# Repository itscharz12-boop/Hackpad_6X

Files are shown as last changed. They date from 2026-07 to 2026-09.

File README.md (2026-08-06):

# Hackpad 6x

Hackpad 6x is a small but very over-engineered macropad that I designed because apparently a normal keyboard was not enough :)

The idea was to make a compact control pad that could do a bit of everything: media controls, shortcuts, gaming controls, numpad functions, and displaying useless (but cool) information from my PC.

Basically, I wanted an "infinite keys" macropad where a few buttons could become a lot of buttons through layers.

(Yes, this did start as "I'll just make a simple macropad" and then somehow became OLEDs, RGB, and a PC monitoring system. I have no idea how this happened.)

Images of this hackpad can be found in the "images" folder.

Showcase Video (For Hack Club's Stardance event) also available at this link:
https://drive.google.com/file/d/1NDWkFQftZgt32tnkIbqYFETVVm34cNFE/view?usp=sharing

---

# Quick Start

To build this:

1. **Build the hardware**
   - Assemble the PCB, switches, encoder, OLED and case.
   - (Of course you need a soldering iron for soldering. Unfortunately staring at the PCB does not make the components attach themselves.)

2. **Flash the firmware**
   - Install QMK and flash the firmware onto the Seeed XIAO RP2040.

3. **Install HackpadDataLink**
   - Run the Python script on your PC to send system information to the OLED.

---

# Features

- 5 different profiles/layers
- Rotary encoder with push button
- OLED display
- RGB lighting
- PC telemetry

The PC telemetry shows:
- CPU usage
- GPU usage
- Volume
- Brightness

(Useful for checking your PC performance without moving your eyes approximately 20cm up to look at your monitor.)

---

# Hardware

The hackpad is built around a Seeed XIAO RP2040.

Parts:

- Seeed XIAO RP2040
- 8x Cherry MX switches
- 8x keycaps
- EC11 rotary encoder
- OLED display
- RGB LEDs
- Custom PCB
- 3D printed case

---

# Assembly

### PCB Assembly

Solder all components onto the PCB:

- Diodes
- RGB LEDs
- OLED
- Rotary encoder
- XIAO RP2040

Please please please check the orientation twice, you won't regret it

### Case Assembly

- Install heat-set inserts
- Screw everything together

---

### Firmware

Hackpad 6x uses QMK firmware.

The firmware includes:

- Layer switching
- Encoder controls
- RGB effects
- OLED graphics
- RAW HID PC communication

---

### Hackpad DataLink

HackpadDataLink is a Python script that sends PC information to the hackpad.

Currently supported:

- CPU usage
- GPU usage
- Volume
- Brightness

---

# Images










### AI Usage

AI was used minimally throughout this project. The only instance of AI use was on 4 occasions fixing compile errors in the firmware. This was done with VS code's built in AI. Aside from this, no other AI tools were used in the making of this project.

Hackpad 6x was built as a personal project to learn PCB design, CAD, QMK firmware, and hardware/software integration.

Huge thanks to Hack Club for making this program possible :)

(Also thanks to Google, Stack Overflow, and whoever wrote the forum post that fixed kicad at 1am.)

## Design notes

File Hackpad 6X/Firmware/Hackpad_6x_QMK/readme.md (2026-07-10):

# hackpad_6x_qmk

hackpad_6x_qmk

*A short description of the keyboard/project*

* Keyboard Maintainer: [Charles Z](https://github.com/charz)
* Hardware Supported: *The PCBs, controllers supported*
* Hardware Availability: *Links to where you can find this hardware*

Make example for this keyboard (after setting up your build environment):

    make hackpad_6x_qmk:default

Flashing example for this keyboard:

    make hackpad_6x_qmk:default:flash

See the [build environment setup](https://docs.qmk.fm/#/getting_started_build_tools) and the [make instructions](https://docs.qmk.fm/#/getting_started_make_guide) for more information. Brand new to QMK? Start with our [Complete Newbs Guide](https://docs.qmk.fm/#/newbs).

## Bootloader

Enter the bootloader in 3 ways:

* **Bootmagic reset**: Hold down the key at (0,0) in the matrix (usually the top left key or Escape) and plug in the keyboard
* **Physical reset button**: Briefly press the button on the back of the PCB - some may have pads you must short instead
* **Keycode in layout**: Press the key mapped to `QK_BOOT` if it is available

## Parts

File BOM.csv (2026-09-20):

Component | Quantity
Seeed XIAO RP2040 | 1
Hackpad PCB | 1
MX-compatible switches | 8
MX-compatible keycaps | 8
EC11 rotary encoder | 1
0.91 inch I2C OLED | 1
SK6812 MINI-E LEDs | 18
Diodes | 9
M3 heat-set inserts | 6
M3 screws | 6
3D-printed case top | 1
3D-printed case base | 1

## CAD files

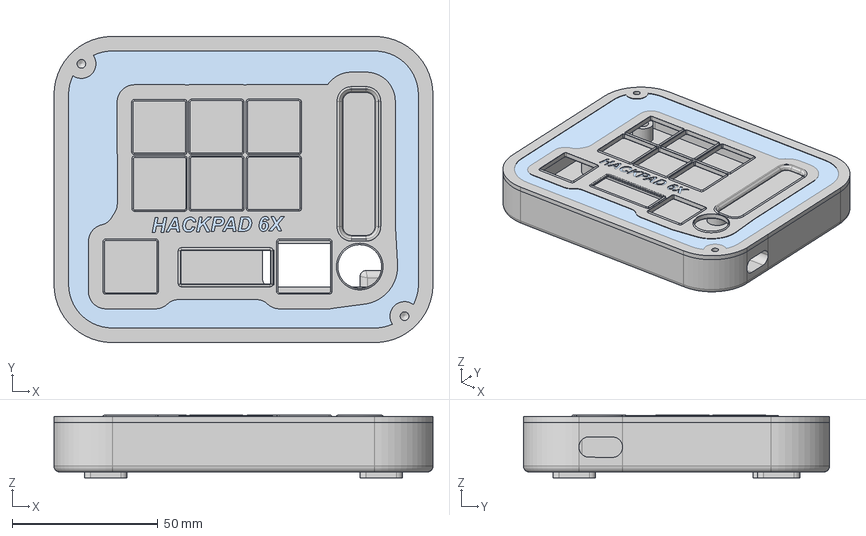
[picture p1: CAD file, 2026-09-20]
Hackpad 6X/CAD/Case.step
130.0 x 105.0 x 21.5 mm

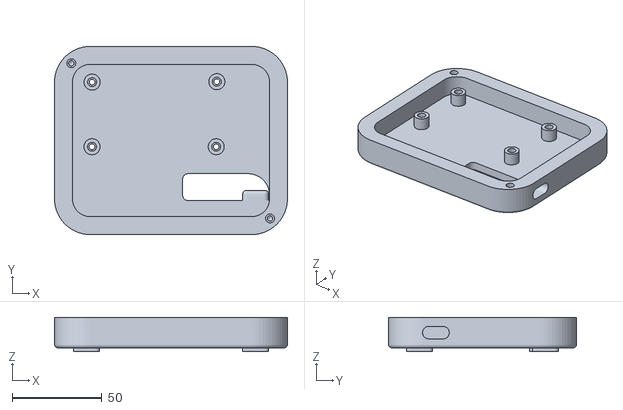
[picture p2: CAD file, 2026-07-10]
Hackpad 6X/Production/Case STL/Base.stl
130.0 x 105.0 x 19.0

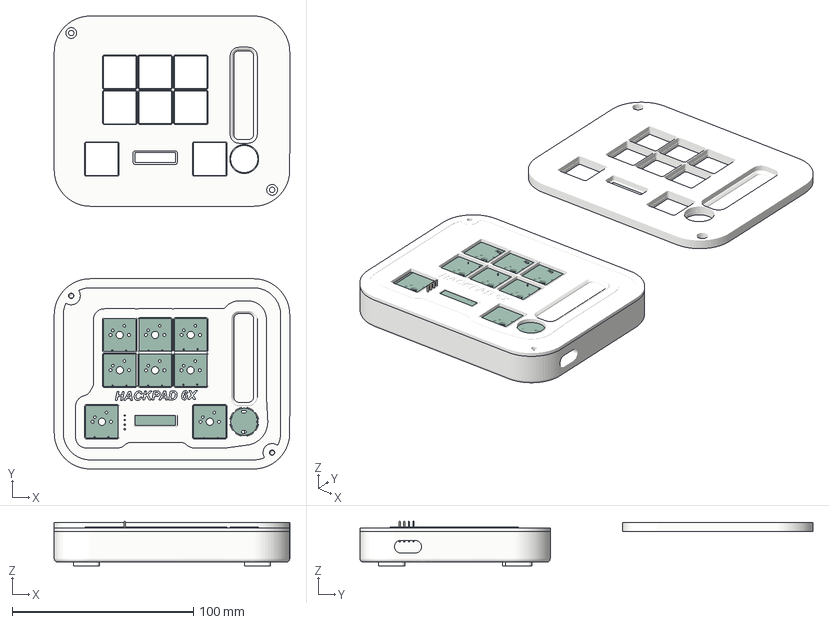
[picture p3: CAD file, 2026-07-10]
Hackpad 6X/CAD/Hackpad.3mf
130.0 x 250.0 x 24.6 mm
Base
Thick Plate (to test)
Top Plate

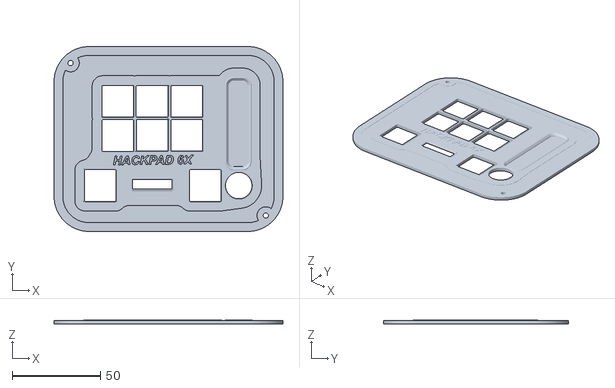
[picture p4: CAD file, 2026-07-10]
Hackpad 6X/Production/Case STL/Top Plate.stl
130.0 x 105.0 x 2.50

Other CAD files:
Hackpad 6X/Production/Case (Top and Bottom).step
Hackpad 6X/CAD/Hackpad.f3z

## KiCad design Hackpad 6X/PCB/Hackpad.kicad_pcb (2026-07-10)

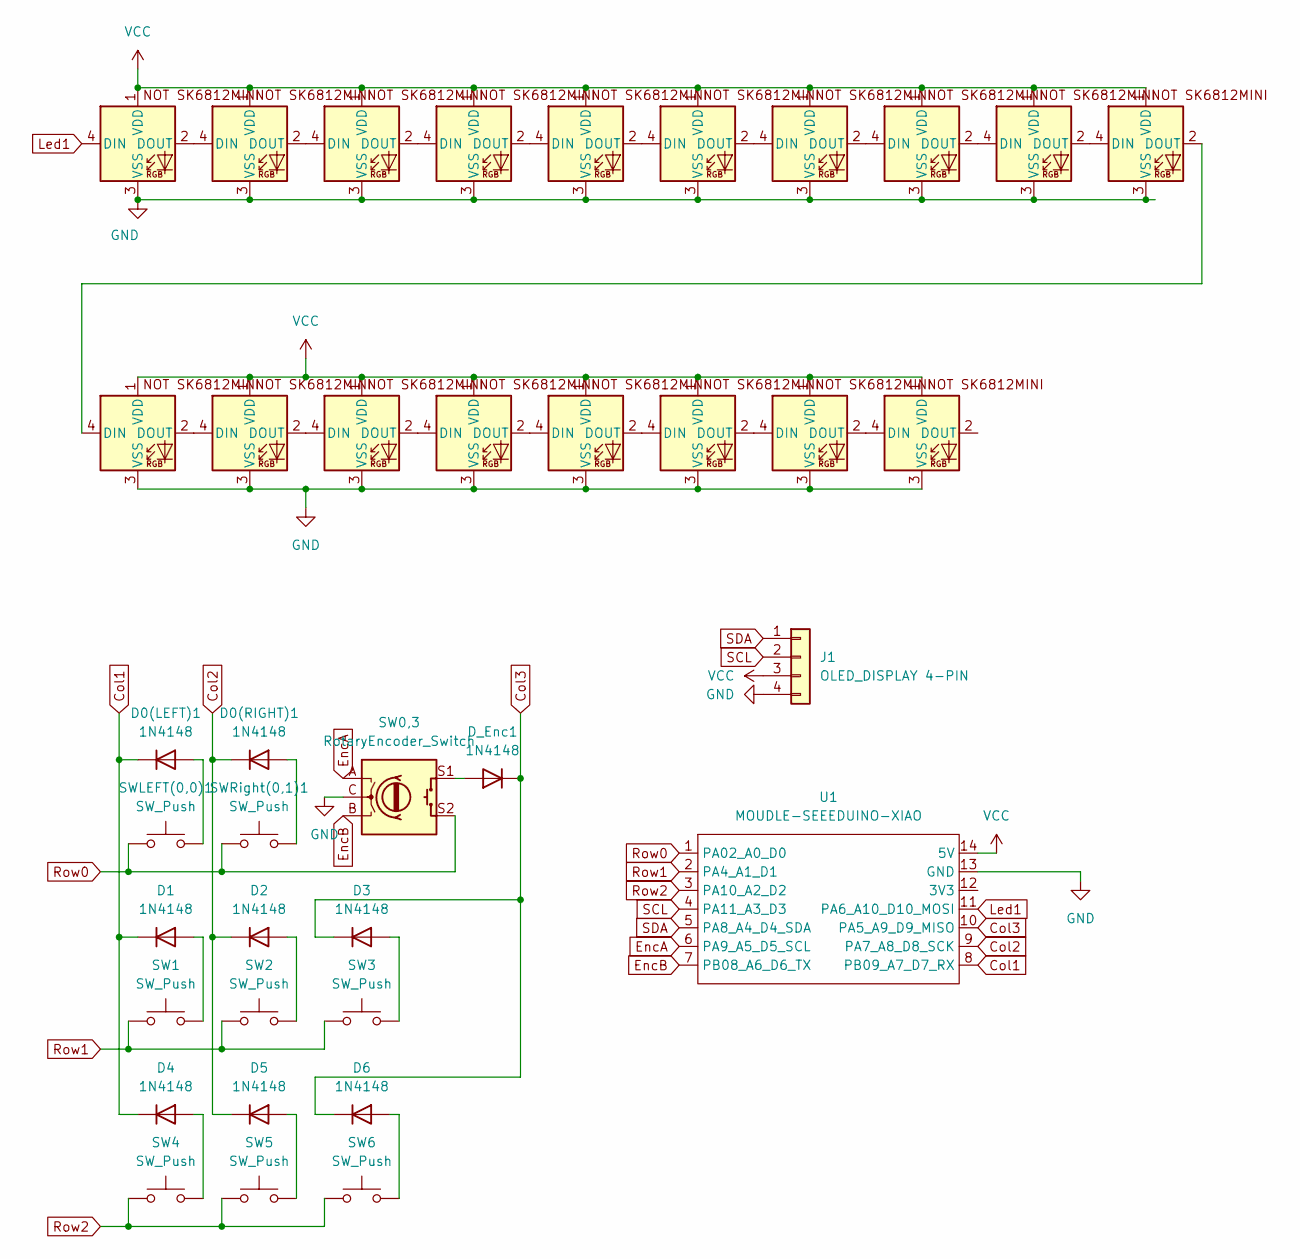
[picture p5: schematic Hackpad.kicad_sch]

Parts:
D0(LEFT)1, D0(RIGHT)1, D1, D2, D3, D4, D5, D6: 1N4148; D_DO-35_SOD27_P7.62mm_Horizontal
D15, D16, D17, D18, D19, D20, D21, D22, D24, D25, D26, D27, D28, D29, D30, D31, D32, D33: SK6812MINI-E; SK6812MINI-E_fixed
D_Enc1: 1N4148; D_DO-35_SOD27_P7.62mm_Horizontal
J1: OLED_DISPLAY 4-PIN; PinHeader_1x04_P2.54mm_Vertical
SW0,3: RotaryEncoder_Switch; RotaryEncoder_Alps_EC11E-Switch_Vertical_H20mm
SW1, SW2, SW3, SW4, SW5, SW6: SW_Push; SW_Cherry_MX_1.00u_PCB
SWLEFT(0,0)1: SW_Push; SW_Cherry_MX_1.00u_PCB
SWRight(0,1)1: SW_Push; SW_Cherry_MX_1.00u_PCB
U1: MOUDLE-SEEEDUINO-XIAO; XIAO-Generic-Hybrid-14P-2.54-21X17.8MM

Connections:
Col1: D0(LEFT)1.1 (K), D1.1 (K), D4.1 (K), U1.8 (PB09_A7_D7_RX)
Col2: D0(RIGHT)1.1 (K), D2.1 (K), D5.1 (K), U1.9 (PA7_A8_D8_SCK)
Col3: D3.1 (K), D6.1 (K), D_Enc1.1 (K), U1.10 (PA5_A9_D9_MISO)
EncA: SW0,3.A, U1.6 (PA9_A5_D5_SCL)
EncB: SW0,3.B, U1.7 (PB08_A6_D6_TX)
GND: D15.3 (VSS), D16.3 (VSS), D17.3 (VSS), D18.3 (VSS), D19.3 (VSS), D20.3 (VSS), D21.3 (VSS), D22.3 (VSS), D24.3 (VSS), D25.3 (VSS), D26.3 (VSS), D27.3 (VSS), D28.3 (VSS), D29.3 (VSS), D30.3 (VSS), D31.3 (VSS), D32.3 (VSS), D33.3 (VSS), J1.4, SW0,3.C, U1.13 (GND)
Led1: D15.4 (DIN), U1.11 (PA6_A10_D10_MOSI)
unnamed: D0(LEFT)1.2 (A), SWLEFT(0,0)1.2
unnamed: D0(RIGHT)1.2 (A), SWRight(0,1)1.2
unnamed: D1.2 (A), SW1.2
unnamed: D2.2 (A), SW2.2
unnamed: D3.2 (A), SW3.2
unnamed: D4.2 (A), SW4.2
unnamed: D5.2 (A), SW5.2
unnamed: D6.2 (A), SW6.2
unnamed: D15.2 (DOUT), D16.4 (DIN)
unnamed: D16.2 (DOUT), D17.4 (DIN)
unnamed: D17.2 (DOUT), D18.4 (DIN)
unnamed: D18.2 (DOUT), D24.4 (DIN)
unnamed: D19.4 (DIN), D29.2 (DOUT)
unnamed: D19.2 (DOUT), D20.4 (DIN)
unnamed: D20.2 (DOUT), D21.4 (DIN)
unnamed: D21.2 (DOUT), D22.4 (DIN)
unnamed: D22.2 (DOUT), D30.4 (DIN)
unnamed: D24.2 (DOUT), D25.4 (DIN)
unnamed: D25.2 (DOUT), D26.4 (DIN)
unnamed: D26.2 (DOUT), D27.4 (DIN)
unnamed: D27.2 (DOUT), D28.4 (DIN)
unnamed: D28.2 (DOUT), D29.4 (DIN)
unnamed: D30.2 (DOUT), D31.4 (DIN)
unnamed: D31.2 (DOUT), D32.4 (DIN)
unnamed: D32.2 (DOUT), D33.4 (DIN)
unnamed: D_Enc1.2 (A), SW0,3.S1
Row0: SW0,3.S2, SWLEFT(0,0)1.1, SWRight(0,1)1.1, U1.1 (PA02_A0_D0)
Row1: SW1.1, SW2.1, SW3.1, U1.2 (PA4_A1_D1)
Row2: SW4.1, SW5.1, SW6.1, U1.3 (PA10_A2_D2)
SCL: J1.2, U1.4 (PA11_A3_D3)
SDA: J1.1, U1.5 (PA8_A4_D4_SDA)
VCC: D15.1 (VDD), D16.1 (VDD), D17.1 (VDD), D18.1 (VDD), D19.1 (VDD), D20.1 (VDD), D21.1 (VDD), D22.1 (VDD), D24.1 (VDD), D25.1 (VDD), D26.1 (VDD), D27.1 (VDD), D28.1 (VDD), D29.1 (VDD), D30.1 (VDD), D31.1 (VDD), D32.1 (VDD), D33.1 (VDD), J1.3, U1.14 (5V)

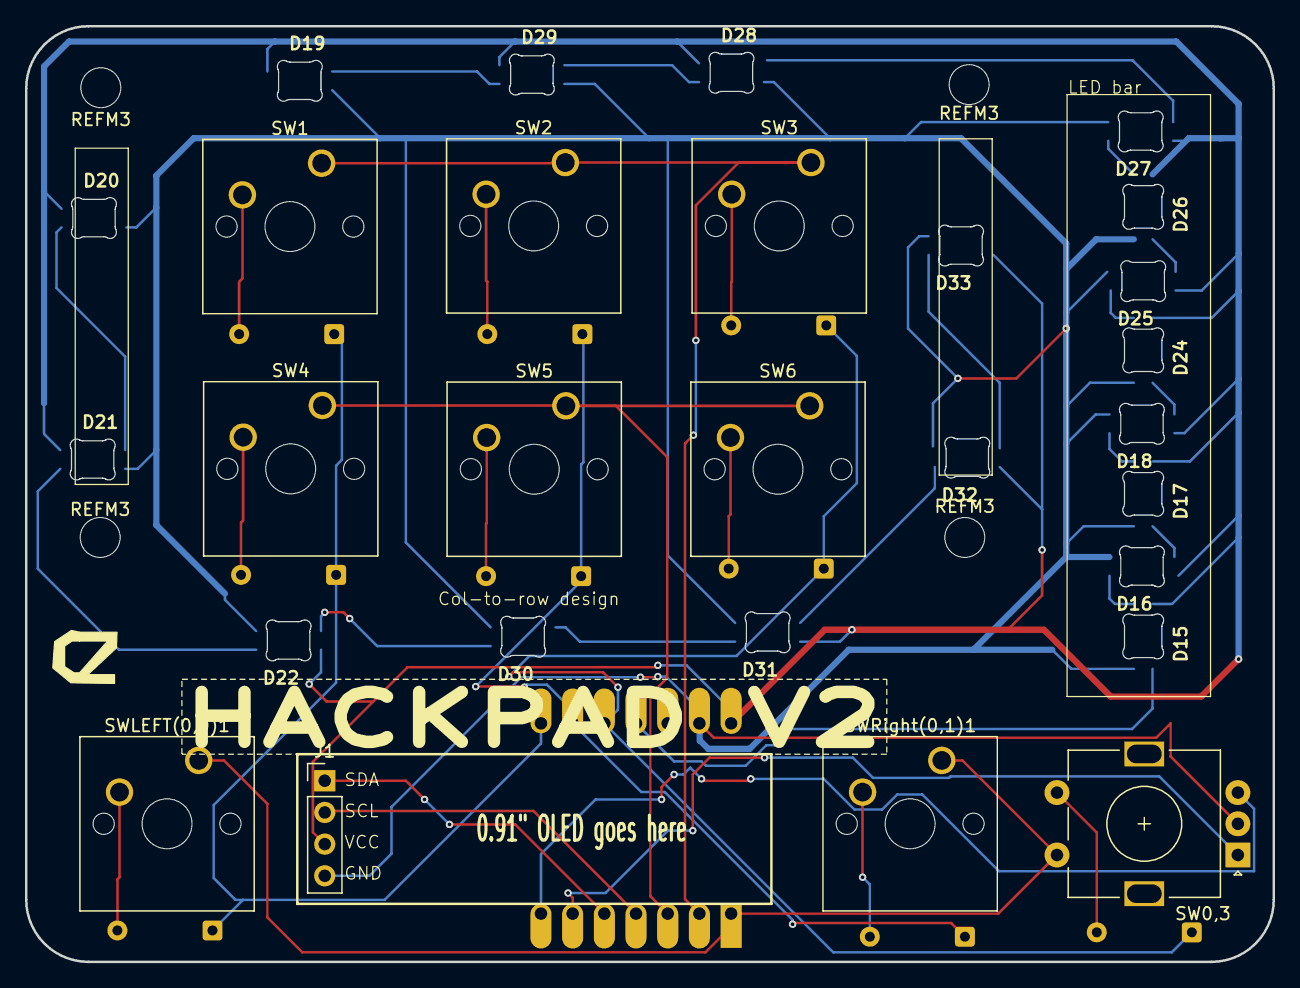
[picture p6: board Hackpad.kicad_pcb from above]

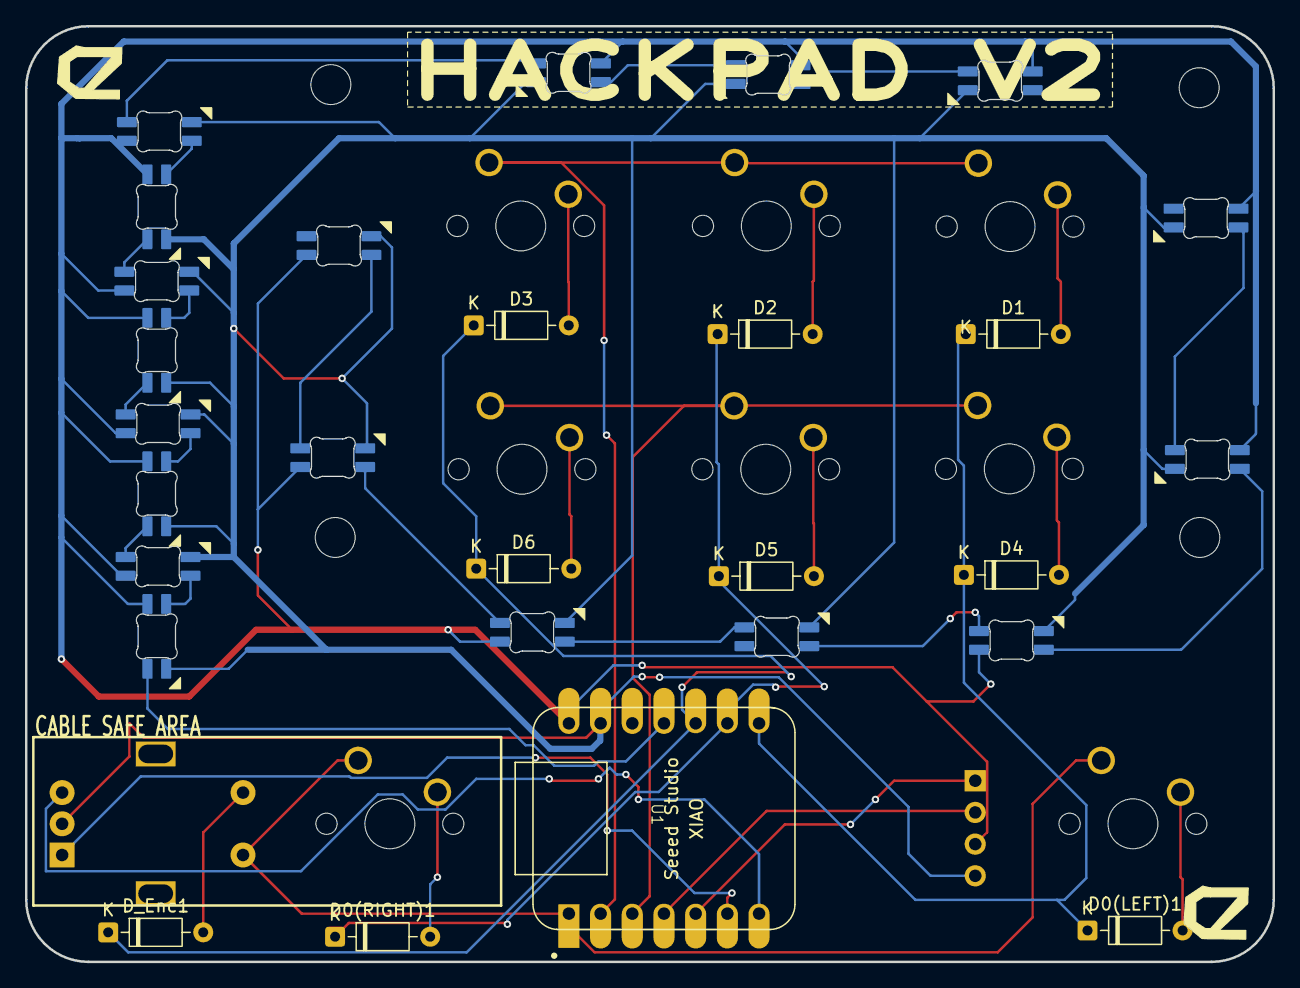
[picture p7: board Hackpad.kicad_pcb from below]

Board: 2 copper layers, 100.0 x 75.0 mm, 42 parts (10 on the bottom side), 39 nets.

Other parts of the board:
REFM3, REFM3#2, REFM3#3, REFM3#4: MountingHole_3.2mm_M3

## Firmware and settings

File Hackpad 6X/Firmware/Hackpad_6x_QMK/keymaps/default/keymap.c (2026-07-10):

#include QMK_KEYBOARD_H
#include <stdio.h>

#define RGB_COUNT 18
#define METER_LED_COUNT 8


///// define the variables /////



enum custom_keycodes {
    ENC_MOD = SAFE_RANGE,
    PROF_NEXT,
    PROF_PREV,
    SCR_LEFT,
    SCR_RIGHT,
    HCK_RGB,
    NVIDIA,
    REPLAY,
};

static bool enc_mod = false;
static uint16_t enc_indicator_timer = 0;
static bool enc_recently_used = false;

#define ENC_INDICATOR_TIMEOUT 500  // ms the red/white/red bar stays on after turning encoder


///// RGB effect state /////
// 0 = teal
// 1 = white
// 2 = rainbow radial
// 3 = purple / white / blue effect
// 4 = off

static uint8_t rgb_effect_mode = 0;



///// getting CPU/GPU % /////



// placeholder values until script to send over USB is complete
__attribute__((unused)) static uint8_t raw_cpu_usage = 88;
__attribute__((unused)) static uint8_t raw_gpu_usage = 88;
__attribute__((unused)) static uint8_t pc_vol = 50;
__attribute__((unused)) static uint8_t pc_bright = 50;



/////bitmaps/////



// empty bitmap
static const uint8_t PROGMEM empty_bitmap[] = {
0xff, 0xff, 0xff, 0x80, 0x00, 0x00, 0x00, 0x00, 0x00, 0x00, 0x00, 0x00, 0x03, 0xff, 0xff, 0xff, 
0xff, 0xff, 0xff, 0x9f, 0xff, 0xff, 0xcf, 0xff, 0xff, 0xe7, 0xff, 0xff, 0xf3, 0xff, 0xff, 0xff, 
0xff, 0xff, 0xff, 0x9f, 0xff, 0xff, 0xcf, 0xff, 0xff, 0xe7, 0xff, 0xff, 0xf3, 0xff, 0xff, 0xff, 
0xff, 0xff, 0xff, 0x9f, 0xff, 0xff, 0xcf, 0xff, 0xff, 0xe7, 0xff, 0xff, 0xf3, 0xff, 0xff, 0xff, 
0xff, 0xff, 0xff, 0x9f, 0xff, 0xff, 0xcf, 0xff, 0xff, 0xe7, 0xff, 0xff, 0xf3, 0xff, 0xff, 0xff, 
0xff, 0xff, 0xff, 0x9f, 0xff, 0xff, 0xcf, 0xff, 0xff, 0xe7, 0xff, 0xff, 0xf3, 0xff, 0xff, 0xff, 
0xff, 0xff, 0xff, 0x9f, 0xff, 0xff, 0xcf, 0xff, 0xff, 0xe7, 0xff, 0xff, 0xf3, 0xff, 0xff, 0xff, 
0xff, 0xff, 0xff, 0x9f, 0xff, 0xff, 0xcf, 0xff, 0xff, 0xe7, 0xff, 0xff, 0xf3, 0xff, 0xff, 0xff, 
0xff, 0xff, 0xff, 0x9f, 0xff, 0xff, 0xcf, 0xff, 0xff, 0xe7, 0xff, 0xff, 0xf3, 0xff, 0xff, 0xff, 
0xff, 0xff, 0xff, 0x9f, 0xff, 0xff, 0xcf, 0xff, 0xff, 0xe7, 0xff, 0xff, 0xf3, 0xff, 0xff, 0xff, 
0xff, 0xff, 0xff, 0x9f, 0xff, 0xff, 0xcf, 0xff, 0xff, 0xe7, 0xff, 0xff, 0xf3, 0xff, 0xff, 0xff, 
0xff, 0xff, 0xff, 0x9f, 0xff, 0xff, 0xcf, 0xff, 0xff, 0xe7, 0xff, 0xff, 0xf3, 0xff, 0xff, 0xff, 
0xff, 0xff, 0xff, 0x9f, 0xff, 0xff, 0xcf, 0xff, 0xff, 0xe7, 0xff, 0xff, 0xf3, 0xff, 0xff, 0xff, 
0xff, 0xff, 0xff, 0x9f, 0xff, 0xff, 0xcf, 0xff, 0xff, 0xe7, 0xff, 0xff, 0xf3, 0xff, 0xff, 0xff, 
0xff, 0xff, 0xff, 0x9f, 0xff, 0xff, 0xcf, 0xff, 0xff, 0xe7, 0xff, 0xff, 0xf3, 0xff, 0xff, 0xff, 
0xff, 0xff, 0xff, 0x80, 0x00, 0x00, 0x00, 0x00, 0x00, 0x00, 0x00, 0x00, 0x03, 0xff, 0xff, 0xff, 
0xff, 0xff, 0xff, 0x80, 0x00, 0x00, 0x00, 0x00, 0x00, 0x00, 0x00, 0x00, 0x03, 0xff, 0xff, 0xff, 
0xff, 0xff, 0xff, 0x9f, 0xff, 0xff, 0xcf, 0xff, 0xff, 0xe7, 0xff, 0xff, 0xf3, 0xff, 0xff, 0xff, 
0xff, 0xff, 0xff, 0x9f, 0xff, 0xff, 0xcf, 0xff, 0xff, 0xe7, 0xff, 0xff, 0xf3, 0xff, 0xff, 0xff, 
0xff, 0xff, 0xff, 0x9f, 0xff, 0xff, 0xcf, 0xff, 0xff, 0xe7, 0xff, 0xff, 0xf3, 0xff, 0xff, 0xff, 
0xff, 0xff, 0xff, 0x9f, 0xff, 0xff, 0xcf, 0xff, 0xff, 0xe7, 0xff, 0xff, 0xf3, 0xff, 0xff, 0xff, 
0xff, 0xff, 0xff, 0x9f, 0xff, 0xff, 0xcf, 0xff, 0xff, 0xe7, 0xff, 0xff, 0xf3, 0xff, 0xff, 0xff, 
0xff, 0xff, 0xff, 0x9f, 0xff, 0xff, 0xcf, 0xff, 0xff, 0xe7, 0xff, 0xff, 0xf3, 0xff, 0xff, 0xff, 
0xff, 0xff, 0xff, 0x9f, 0xff, 0xff, 0xcf, 0xff, 0xff, 0xe7, 0xff, 0xff, 0xf3, 0xff, 0xff, 0xff, 
0xf5, 0x88, 0x5b, 0x9f, 0xff, 0xff, 0xcf, 0xff, 0xff, 0xe7, 0xff, 0xff, 0xf3, 0xac, 0x42, 0xdf, 
0xfd, 0x7b, 0x5b, 0x9f, 0xff, 0xff, 0xcf, 0xff, 0xff, 0xe7, 0xff, 0xff, 0xf3, 0xeb, 0xda, 0xdf, 
0xfb, 0x7b, 0x5b, 0x9f, 0xff, 0xff, 0xcf, 0xff, 0xff, 0xe7, 0xff, 0xff, 0xf3, 0xdb, 0xda, 0xdf, 
0xfb, 0x78, 0xdb, 0x9f, 0xff, 0xff, 0xcf, 0xff, 0xff, 0xe7, 0xff, 0xff, 0xf3, 0xda, 0x46, 0xdf, 
0xf7, 0x7b, 0xdb, 0x9f, 0xff, 0xff, 0xcf, 0xff, 0xff, 0xe7, 0xff, 0xff, 0xf3, 0xbb, 0x5e, 0xdf, 
0xf5, 0x8b, 0xe7, 0x9f, 0xff, 0xff, 0xcf, 0xff, 0xff, 0xe7, 0xff, 0xff, 0xf3, 0xac, 0xdf, 0x3f, 
0xff, 0xff, 0xff, 0x9f, 0xff, 0xff, 0xcf, 0xff, 0xff, 0xe7, 0xff, 0xff, 0xf3, 0xff, 0xff, 0xff, 
0xff, 0xff, 0xff, 0x80, 0x00, 0x00, 0x00, 0x00, 0x00, 0x00, 0x00, 0x00, 0x03, 0xff, 0xff, 0xff
};
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

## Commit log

2026-07-10 Added all files from hackpad folder
    [Base.stl, Hackpad.3mf, Hackpad.f3z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]
2026-08-06 Rename Screenshot 2026-07-09 213341.png to Case
2026-08-06 Rename Screenshot 2026-07-09 213408.png to Case Base
2026-08-06 Rename Screenshot 2026-07-09 213421.png to Case (Unrendered)
2026-08-06 Rename Screenshot 2026-07-09 213603.png to PCB schematic
2026-08-06 Rename Screenshot 2026-07-09 213625.png to PCB (No Traces)
2026-08-06 Rename Screenshot 2026-07-09 213747.png to PCB 3D model
2026-08-06 Rename Screenshot 2026-07-09 213803.png to PCB 3D Model (Rear)
2026-09-20 Add BOM.csv with component list and quantities
    [BOM.csv]
